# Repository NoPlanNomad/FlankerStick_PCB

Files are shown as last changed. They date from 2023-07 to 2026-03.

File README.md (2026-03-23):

# FlankerStick_PCBs
 
PCB's designed for my Flanker Style DIY Hotas stick.

https://cults3d.com/en/3d-model/game/flanker-style-stick

https://www.cgtrader.com/3d-print-models/hobby-diy/mechanical-parts/flanker-style-stick

# BOM
## GripLogic_FreeJoy
|quantaty | Type:Value |Footprint|
|---|---|---|
|2 |Capacitor : 0.1uF|0805 |
|9 |Resistor  : 1K |0805 |
|2 |74HC165 |TSSOP-16 |
|2 |JST_XH:B5B-XH-A  |P2.50 mm |
|4 |JST_XH:B2B-XH-A  |P2.50 mm |
|2 |JST_XH:B7B-XH-A  |P2.50 mm |

## HeadLogic_FreeJoy
|quantaty | Type:Value |Footprint|
|---|---|---|
|3 |Capacitor : 0.1uF|0805 |
|24 |Resitor : 1K |0805 |
|3 |74HC165 |TSSOP-16 |
|4 |JST_XH:B7B-XH-A  |P2.50 mm |
|4 |JST_XH:B2B-XH-A  |P2.50 mm |
|1 |JST_XH:B5B-XH-A  |P2.50 mm |

## Breaklever_FreeJoy
|quantaty | Type:Value |Footprint|
|---|---|---|
|1 |SS495A |TH |
|1 |MCP3201 |SOIC 3.9 |
|1 |JST_XH:B5B-XH-A  |P2.50 mm |

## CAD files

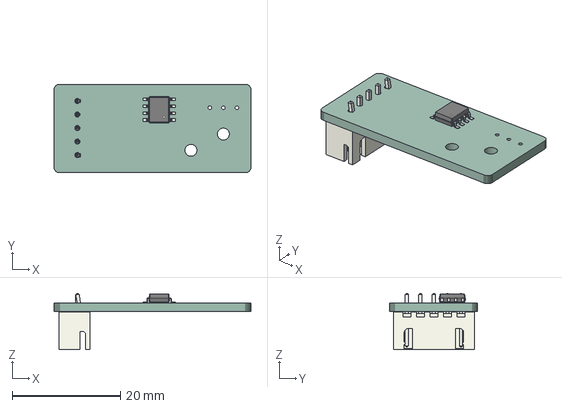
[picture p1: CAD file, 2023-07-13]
LH_BreakLever_FreeJoy/LH_BreakLever_FreeJoy.step
36.4 x 16.4 x 10.4 mm
_autosave-LH_BreakLever_FreeJoy PCB

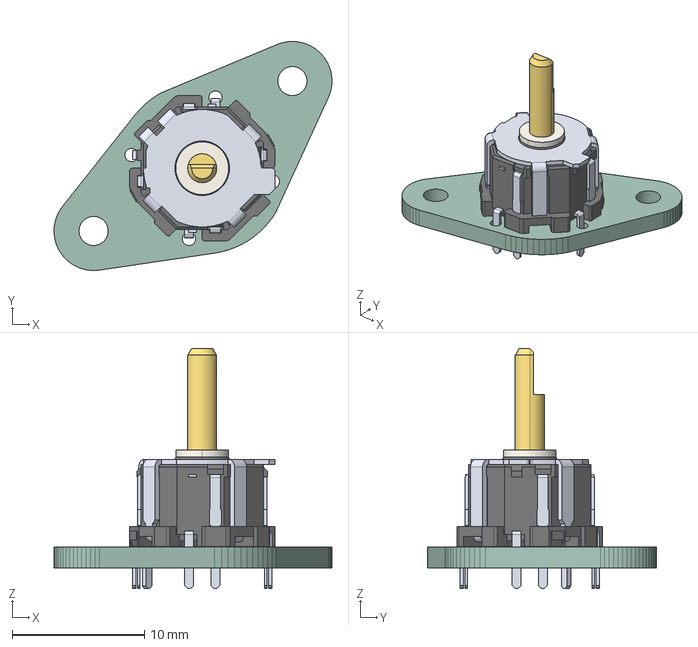
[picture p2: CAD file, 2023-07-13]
RH_RKJXM1015004_FacePlateTilted/RH_RKJXM1015004_FacePlateTilted.step
21.1 x 17.3 x 18.2 mm
RH_RKJXM1015004_FacePlateTilted PCB

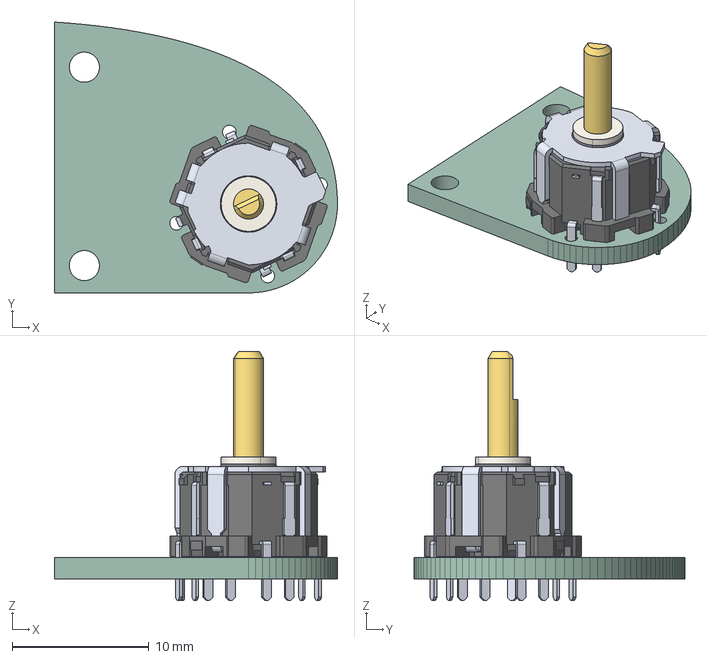
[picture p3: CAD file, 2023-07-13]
RH_RKJXM1015004_thumb/RH_RKJXM1015004_thumb.step
20.7 x 19.8 x 18.2 mm
_autosave-RH_RKJXM1015004_thumb PCB

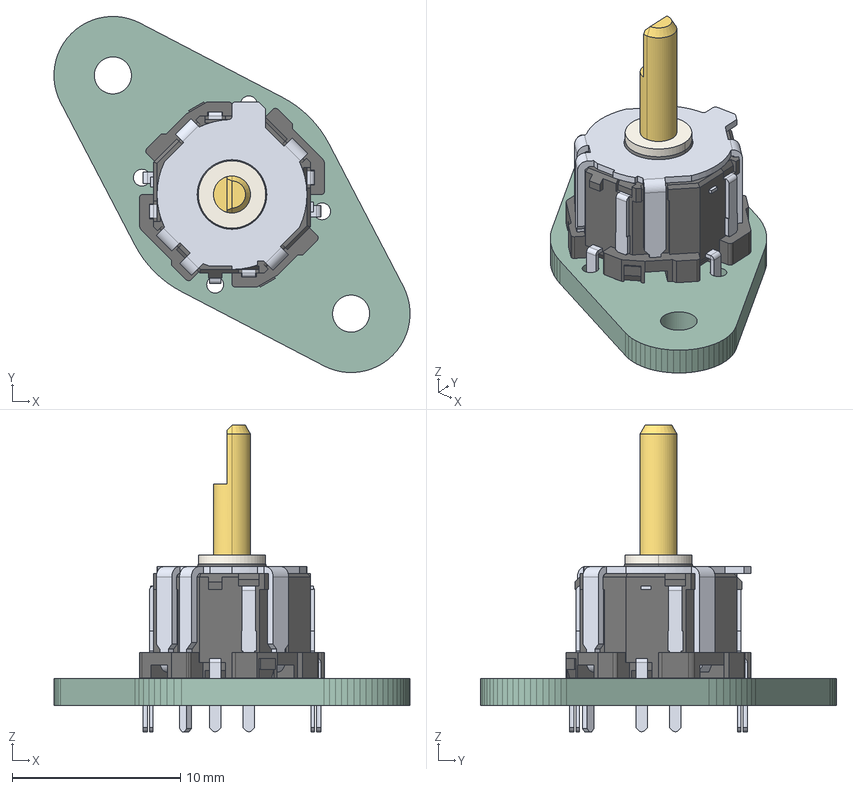
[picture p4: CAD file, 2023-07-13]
RKJXM1015004_Angled/RKJXM1015004_Angled.step
21.1 x 21.1 x 18.2 mm
_autosave-RKJXM1015004_Angled PCB

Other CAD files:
RH_BreakLever_FreeJoy/RH_BreakLever_FreeJoy.step
RKJXM1015004_Straight/RKJXM1015004_Straight.step

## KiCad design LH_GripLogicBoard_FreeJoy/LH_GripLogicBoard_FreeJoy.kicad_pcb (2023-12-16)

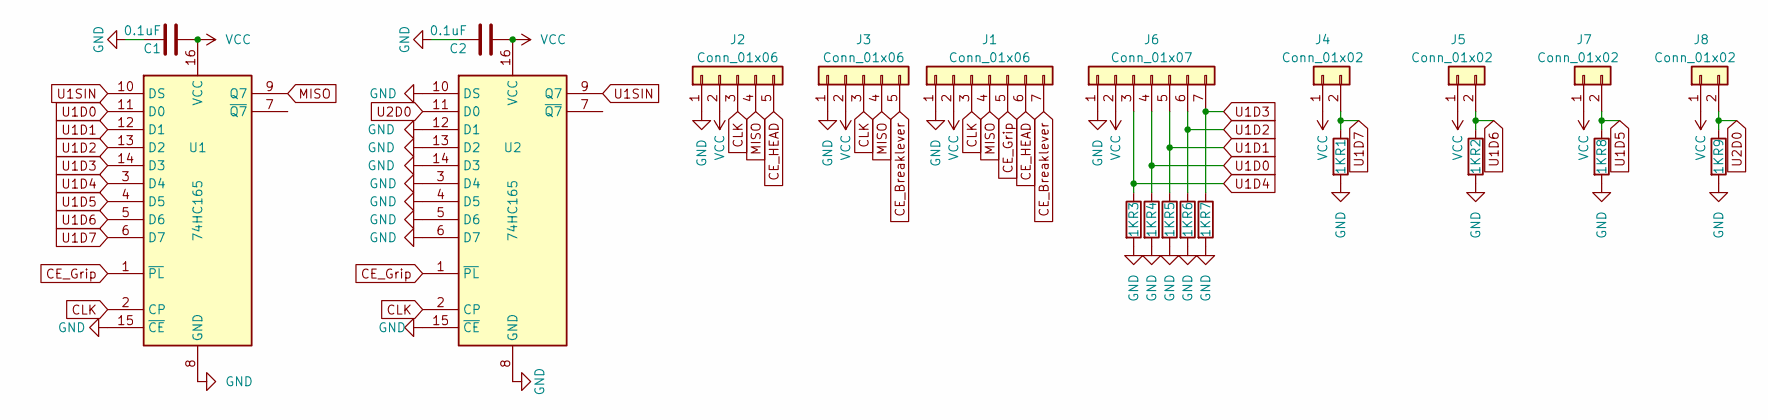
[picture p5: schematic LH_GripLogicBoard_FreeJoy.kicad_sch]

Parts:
C1, C2: 0.1uF; C_0805_2012Metric_Pad1.18x1.45mm_HandSolder
J1: Conn_01x06; JST_XH_B7B-XH-A_1x07_P2.50mm_Vertical
J2, J3: Conn_01x06; JST_XH_B5B-XH-A_1x05_P2.50mm_Vertical
J4, J5, J7, J8: Conn_01x02; JST_XH_B2B-XH-A_1x02_P2.50mm_Vertical
J6: Conn_01x07; JST_XH_B7B-XH-A_1x07_P2.50mm_Vertical
R1, R2, R3, R4, R5, R6, R7, R8, R9: 1K; R_0805_2012Metric_Pad1.20x1.40mm_HandSolder
U1, U2: 74HC165; TSSOP-16_4.4x5mm_P0.65mm

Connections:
CE_Breaklever: J1.7, J3.5
CE_Grip: J1.5, U1.1 (~PL), U2.1 (~PL)
CE_HEAD: J1.6, J2.5
CLK: J1.3, J2.3, J3.3, U1.2 (CP), U2.2 (CP)
GND: C1.1, C2.1, J1.1, J2.1, J3.1, J6.1, R1.2, R2.2, R3.2, R4.2, R5.2, R6.2, R7.2, R8.2, R9.2, U1.8 (GND), U1.15 (~CE), U2.3 (D4), U2.4 (D5), U2.5 (D6), U2.6 (D7), U2.8 (GND), U2.10 (DS), U2.12 (D1), U2.13 (D2), U2.14 (D3), U2.15 (~CE)
MISO: J1.4, J2.4, J3.4, U1.9 (Q7)
U1D0: J6.4, R4.1, U1.11 (D0)
U1D1: J6.5, R5.1, U1.12 (D1)
U1D2: J6.6, R6.1, U1.13 (D2)
U1D3: J6.7, R7.1, U1.14 (D3)
U1D4: J6.3, R3.1, U1.3 (D4)
U1D5: J7.2, R8.1, U1.4 (D5)
U1D6: J5.2, R2.1, U1.5 (D6)
U1D7: J4.2, R1.1, U1.6 (D7)
U1SIN: U1.10 (DS), U2.9 (Q7)
U2D0: J8.2, R9.1, U2.11 (D0)
VCC: C1.2, C2.2, J1.2, J2.2, J3.2, J4.1, J5.1, J6.2, J7.1, J8.1, U1.16 (VCC), U2.16 (VCC)

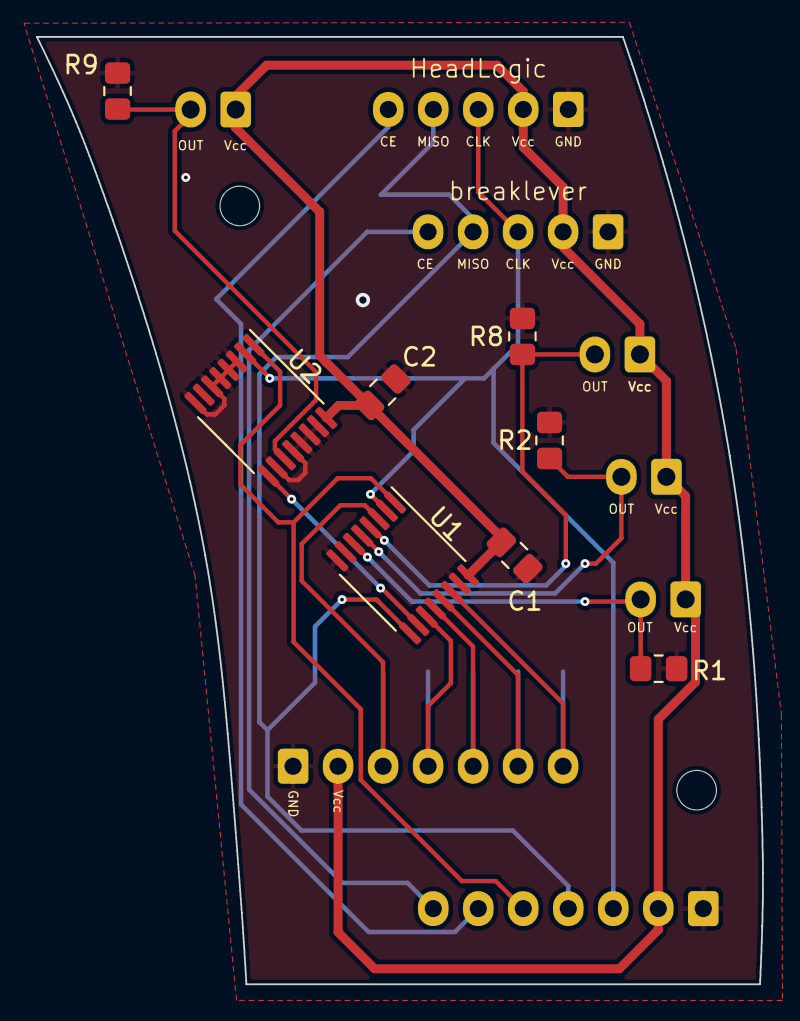
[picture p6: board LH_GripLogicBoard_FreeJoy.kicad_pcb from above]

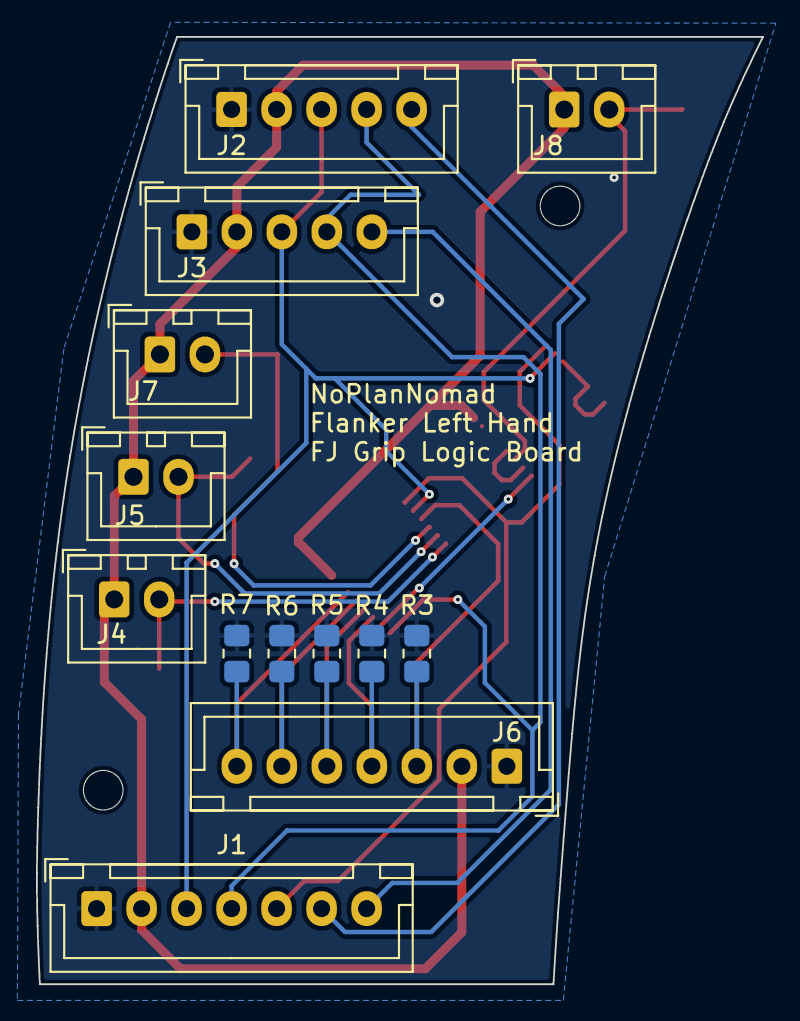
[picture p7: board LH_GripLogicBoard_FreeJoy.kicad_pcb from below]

Board: 2 copper layers, 40.3 x 52.6 mm, 21 parts (13 on the bottom side), 17 nets.

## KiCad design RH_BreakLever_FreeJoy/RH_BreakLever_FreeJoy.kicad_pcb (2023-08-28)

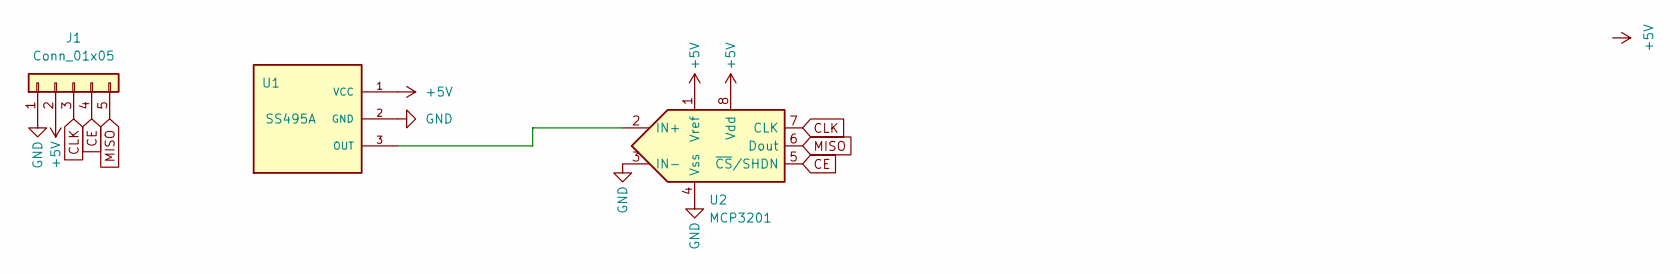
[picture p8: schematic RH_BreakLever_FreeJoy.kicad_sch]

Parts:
J1: Conn_01x05; JST_XH_B5B-XH-A_1x05_P2.50mm_Vertical
U1: SS495A; SS49E-T2; PARTREV Issue 3
U2: MCP3201; SOIC-8_3.9x4.9mm_P1.27mm

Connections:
+5V: J1.2, U1.1 (VCC), U2.1 (Vref), U2.8 (Vdd)
CE: J1.4, U2.5 (~CS/SHDN)
CLK: J1.3, U2.7 (CLK)
GND: J1.1, U1.2 (GND), U2.3 (IN-), U2.4 (Vss)
MISO: J1.5, U2.6 (Dout)
unnamed: U1.3 (OUT), U2.2 (IN+)

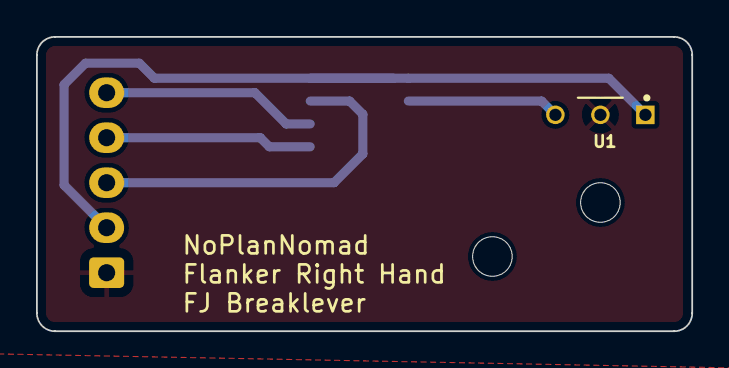
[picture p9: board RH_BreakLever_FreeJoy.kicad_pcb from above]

Board: 2 copper layers, 36.4 x 16.3 mm, 5 parts (1 on the bottom side), 6 nets.

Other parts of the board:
M1, M2: MountingHole_2.2mm_M2

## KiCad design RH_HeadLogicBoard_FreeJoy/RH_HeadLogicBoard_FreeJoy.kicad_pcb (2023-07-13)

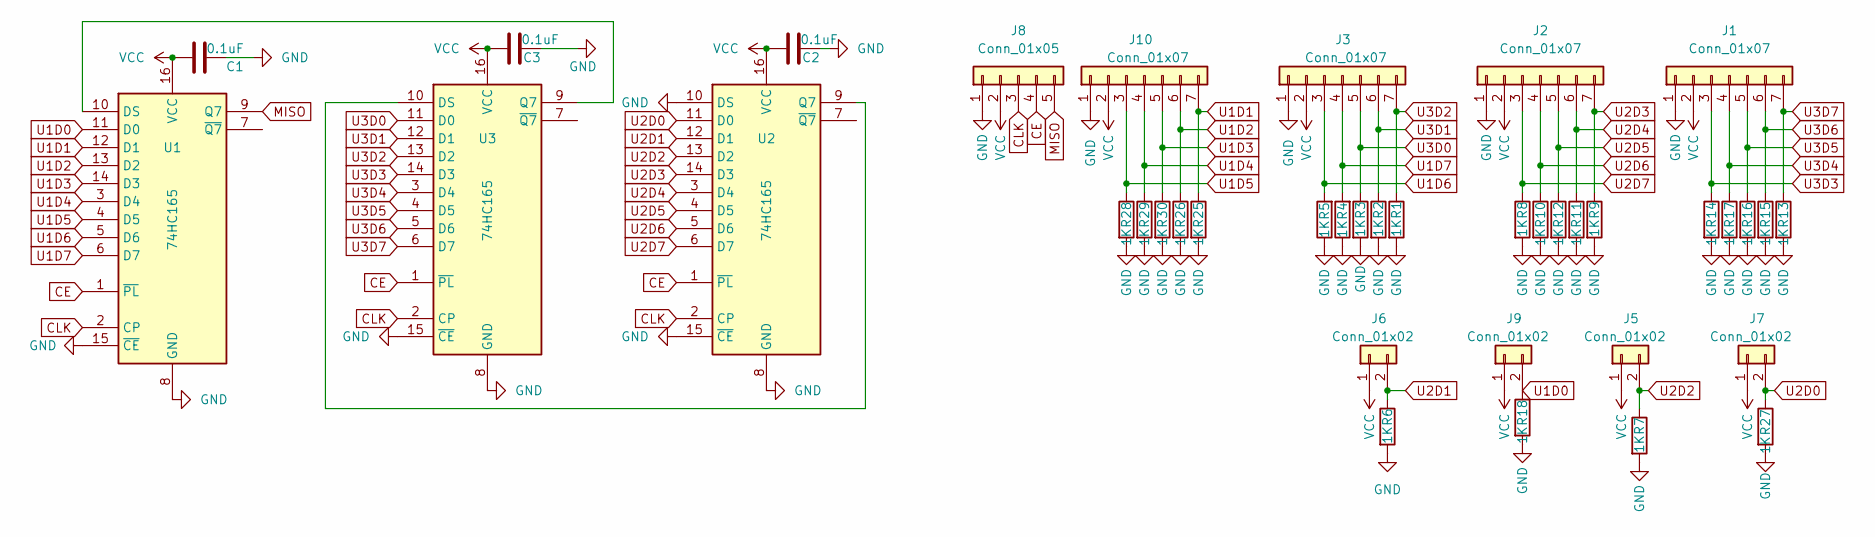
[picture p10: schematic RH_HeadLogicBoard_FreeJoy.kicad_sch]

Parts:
C1, C2, C3: 0.1uF; C_0805_2012Metric_Pad1.18x1.45mm_HandSolder
J1, J2, J3, J10: Conn_01x07; JST_XH_B7B-XH-A_1x07_P2.50mm_Vertical
J5, J6, J7, J9: Conn_01x02; JST_XH_B2B-XH-A_1x02_P2.50mm_Vertical
J8: Conn_01x05; JST_XH_B5B-XH-A_1x05_P2.50mm_Vertical
R1, R2, R3, R4, R5, R6, R7, R8, R9, R10, R11, R12, R13, R14, R15, R16, R17, R18, R25, R26, R27, R28, R29, R30: 1K; R_0805_2012Metric_Pad1.20x1.40mm_HandSolder
U1, U2, U3: 74HC165; TSSOP-16_4.4x5mm_P0.65mm

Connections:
+5V: C1.1, C2.1, C3.1, J1.2, J2.2, J3.2, J5.1, J6.1, J7.1, J8.2, J9.1, J10.2, U1.16 (VCC), U2.16 (VCC), U3.16 (VCC)
CE: J8.4, U1.1 (~PL), U2.1 (~PL), U3.1 (~PL)
CLK: J8.3, U1.2 (CP), U2.2 (CP), U3.2 (CP)
GND: C1.2, C2.2, C3.2, J1.1, J2.1, J3.1, J8.1, J10.1, R1.2, R2.2, R3.2, R4.1, R5.1, R6.2, R7.2, R8.2, R9.2, R10.2, R11.2, R12.2, R13.2, R14.2, R15.2, R16.2, R17.2, R18.2, R25.2, R26.2, R27.2, R28.2, R29.2, R30.2, U1.8 (GND), U1.15 (~CE), U2.8 (GND), U2.10 (DS), U2.15 (~CE), U3.8 (GND), U3.15 (~CE)
MISO: J8.5, U1.9 (Q7)
unnamed: U1.10 (DS), U3.9 (Q7)
unnamed: U2.9 (Q7), U3.10 (DS)
U1D0: J9.2, R18.1, U1.11 (D0)
U1D1: J10.7, R25.1, U1.12 (D1)
U1D2: J10.6, R26.1, U1.13 (D2)
U1D3: J10.5, R30.1, U1.14 (D3)
U1D4: J10.4, R29.1, U1.3 (D4)
U1D5: J10.3, R28.1, U1.4 (D5)
U1D6: J3.3, R5.2, U1.5 (D6)
U1D7: J3.4, R4.2, U1.6 (D7)
U2D0: J7.2, R27.1, U2.11 (D0)
U2D1: J6.2, R6.1, U2.12 (D1)
U2D2: J5.2, R7.1, U2.13 (D2)
U2D3: J2.7, R9.1, U2.14 (D3)
U2D4: J2.6, R11.1, U2.3 (D4)
U2D5: J2.5, R12.1, U2.4 (D5)
U2D6: J2.4, R10.1, U2.5 (D6)
U2D7: J2.3, R8.1, U2.6 (D7)
U3D0: J3.5, R3.1, U3.11 (D0)
U3D1: J3.6, R2.1, U3.12 (D1)
U3D2: J3.7, R1.1, U3.13 (D2)
U3D3: J1.3, R14.1, U3.14 (D3)
U3D4: J1.4, R17.1, U3.3 (D4)
U3D5: J1.5, R16.1, U3.4 (D5)
U3D6: J1.6, R15.1, U3.5 (D6)
U3D7: J1.7, R13.1, U3.6 (D7)

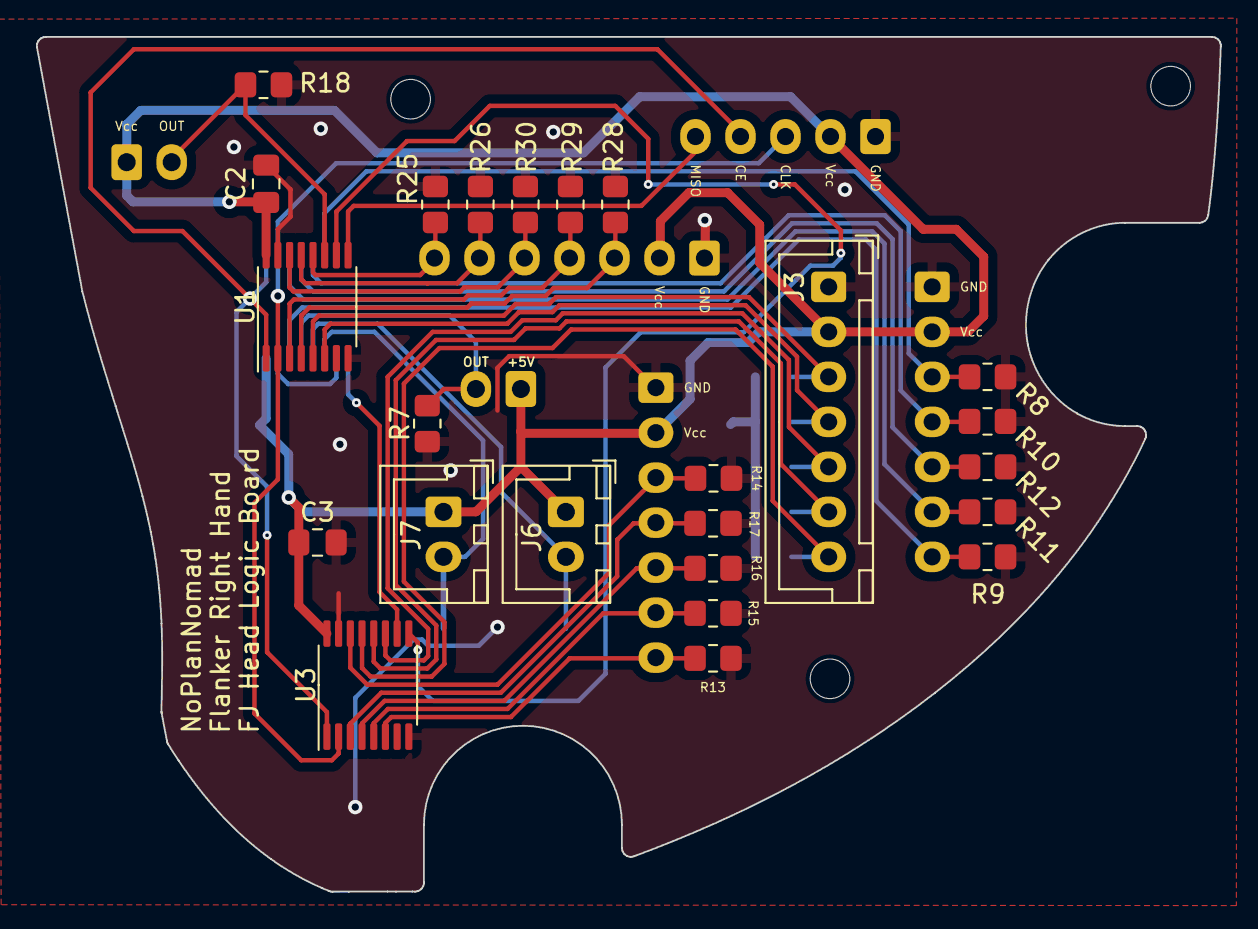
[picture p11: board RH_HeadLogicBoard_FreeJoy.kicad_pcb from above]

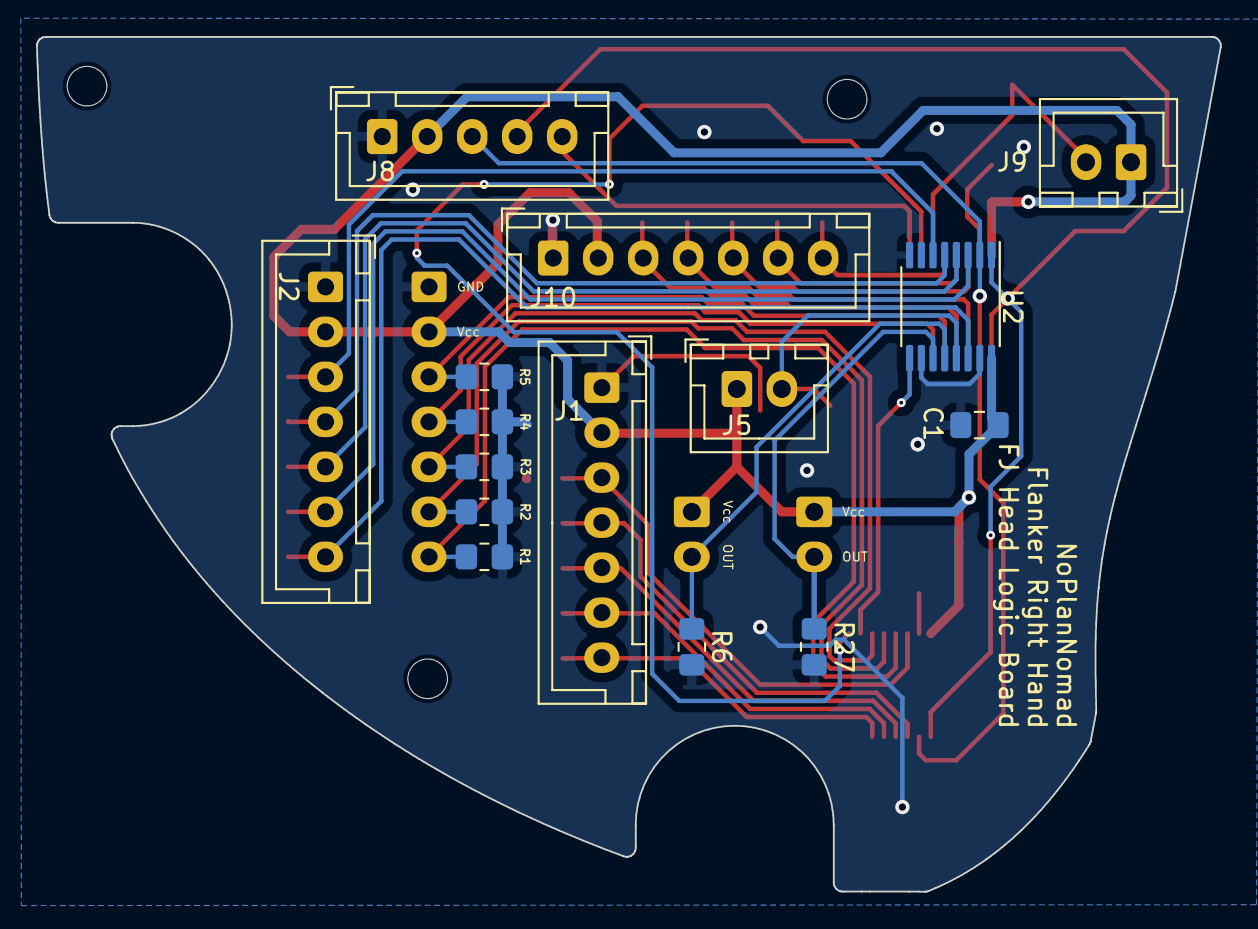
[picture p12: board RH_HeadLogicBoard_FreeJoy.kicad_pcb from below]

Board: 2 copper layers, 65.8 x 47.5 mm, 42 parts (15 on the bottom side), 31 nets.

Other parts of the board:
M1, M2, M3: MountingHole_2.2mm_M2

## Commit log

2023-07-13 added alps kicad submodule
2023-07-13 library fix
    [LH_RKJXM1015004_FacePlateTilted.kicad_pcb, LH_RKJXM1015004_FacePlateTilted.kicad_sch, LH_RKJXM1015004_thumb.kicad_pcb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]
2023-08-28 updated a footprint on Break-lever design for footprint naming.
    [RH_BreakLever_FreeJoy-B_Cu.gbl, RH_BreakLever_FreeJoy-B_Mask.gbs, RH_BreakLever_FreeJoy-B_Paste.gbp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]
2023-12-16 fixed mistake in Grip logic pcb's
    [LH_GripLogicBoard_FreeJoy-B_Cu.gbl, LH_GripLogicBoard_FreeJoy-B_Mask.gbs, LH_GripLogicBoard_FreeJoy-B_Paste.gbp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]
